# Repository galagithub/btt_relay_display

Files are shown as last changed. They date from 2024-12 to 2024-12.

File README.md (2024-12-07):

## BTT Relay Display

A small PCB that can display the status of the relay, it connects to it through a 5 pin cable. A reset switch is also provided.
You can also program/flash the relay through it, there is a separate header for programmer connection.

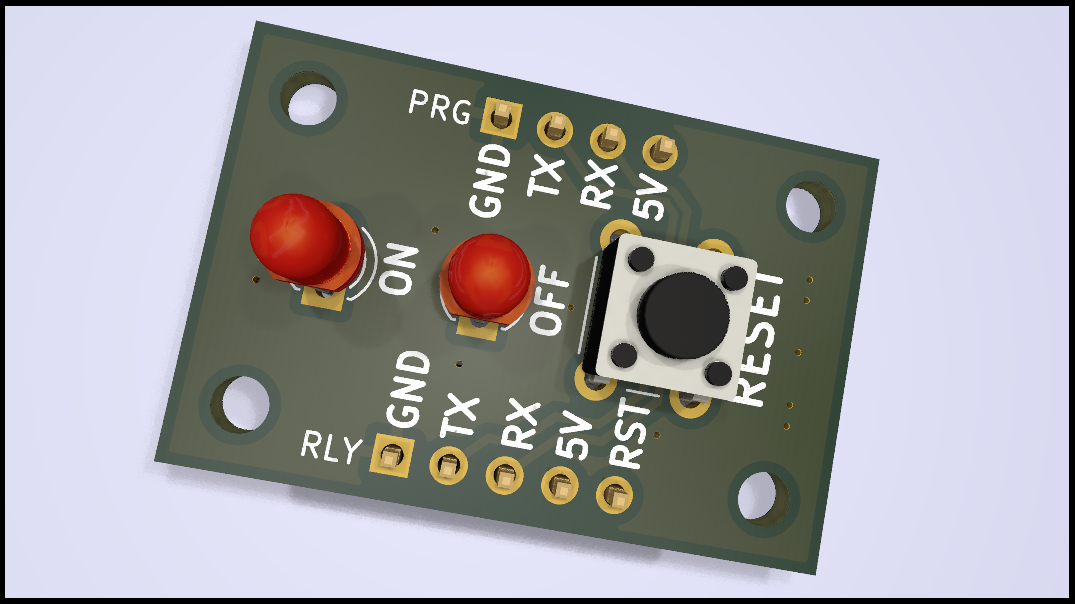
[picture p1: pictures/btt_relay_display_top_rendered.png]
PCB top render


### Related projects
- BTT Relay v1.2 https://github.com/bigtreetech/BIGTREETECH-Relay-V1.2
- Custom firmware with platform.io https://github.com/galagithub/btt_relay_os

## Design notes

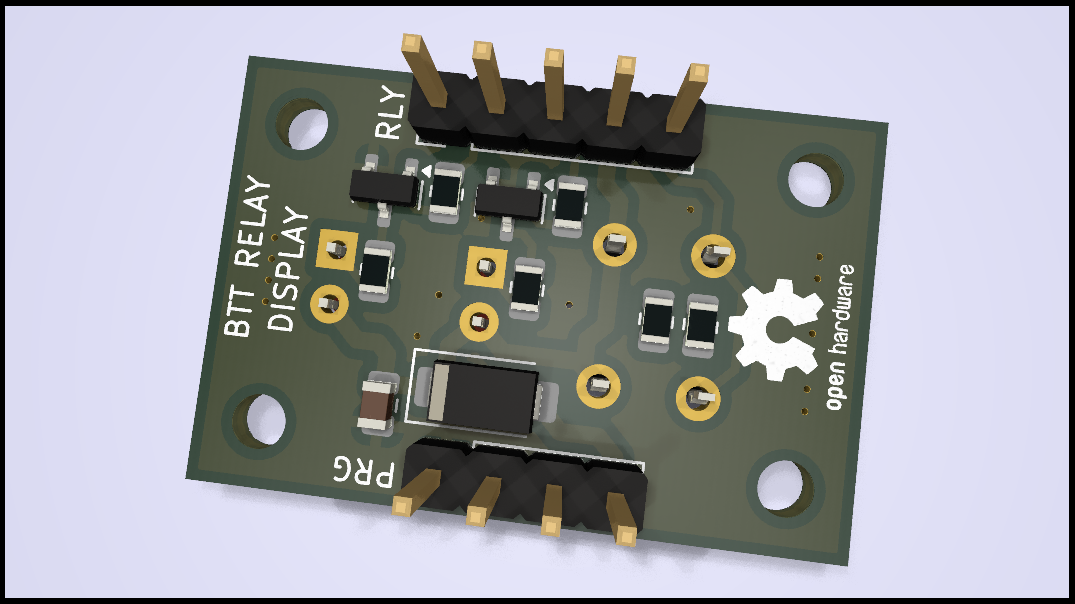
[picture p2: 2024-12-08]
pictures/btt_relay_display_bot_rendered.png

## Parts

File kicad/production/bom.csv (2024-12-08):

Designator | Footprint | Quantity | Value | LCSC Part #
C1 | 0805 | 1 | 1u
D1 | LED_D3.0mm | 1 | OFF (RED)
D2 | LED_D3.0mm | 1 | ON (GRN)
D3 | D_SMA | 1 | SS14
J1 | PinHeader_1x05_P2.54mm_Vertical | 1 | RELAY
J2 | PinHeader_1x04_P2.54mm_Vertical | 1 | PROGRAM
Q1, Q2 | SOT-23 | 2 | BC847
R1, R2, R3, R4 | 0805 | 4 | 1k
R5, R6 | 0805 | 2 | 470
SW1 | SW_PUSH_6mm_H5mm | 1 | RESET

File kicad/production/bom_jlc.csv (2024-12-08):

Designator | Footprint | Quantity | Value | LCSC Part #
C1 | 805 | 1 | 1u
D3 | D_SMA | 1 | SS14
Q1, Q2 | SOT-23 | 2 | BC847
R1, R2, R3, R4 | 805 | 4 | 1k
R5, R6 | 805 | 2 | 470

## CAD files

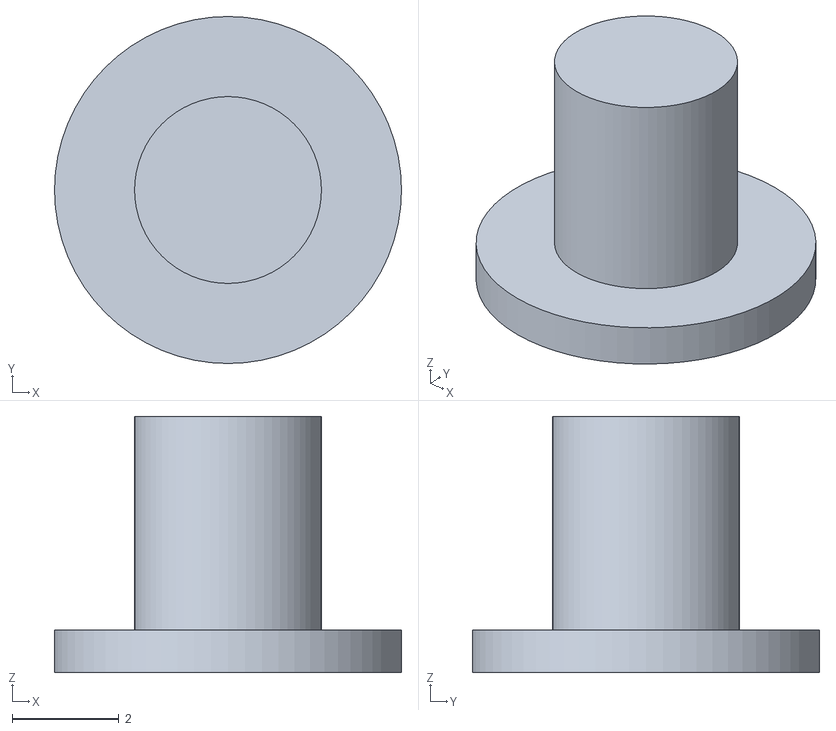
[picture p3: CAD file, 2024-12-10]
stl/front_face_button.stl
6.50 x 6.50 x 4.80

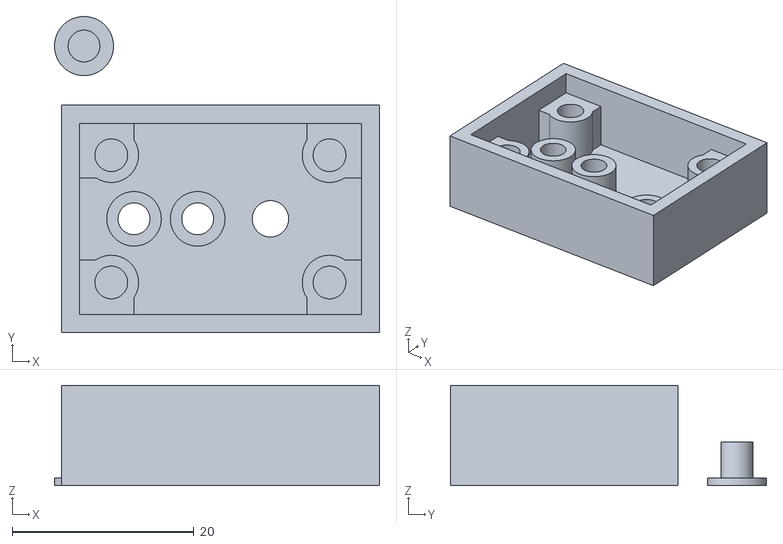
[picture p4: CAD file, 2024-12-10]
stl/front_face_with_button.stl
35.8 x 34.8 x 11.0

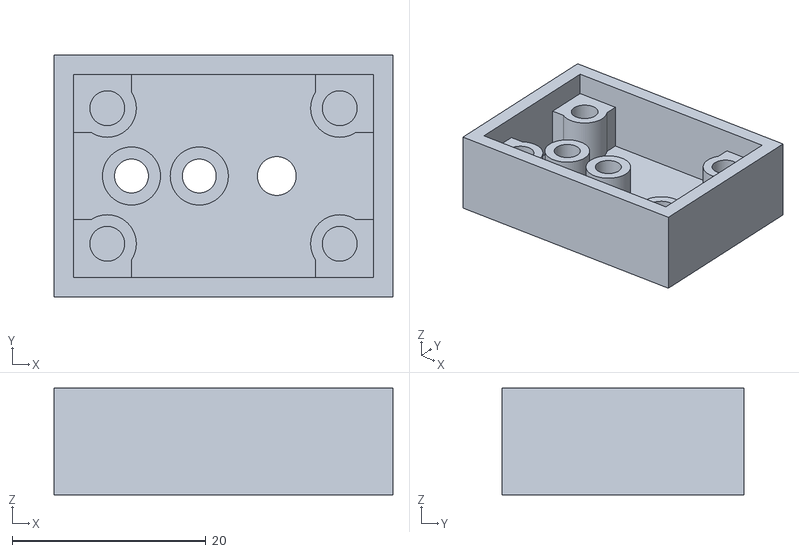
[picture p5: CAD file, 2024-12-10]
stl/front_face.stl
35.0 x 25.0 x 11.0

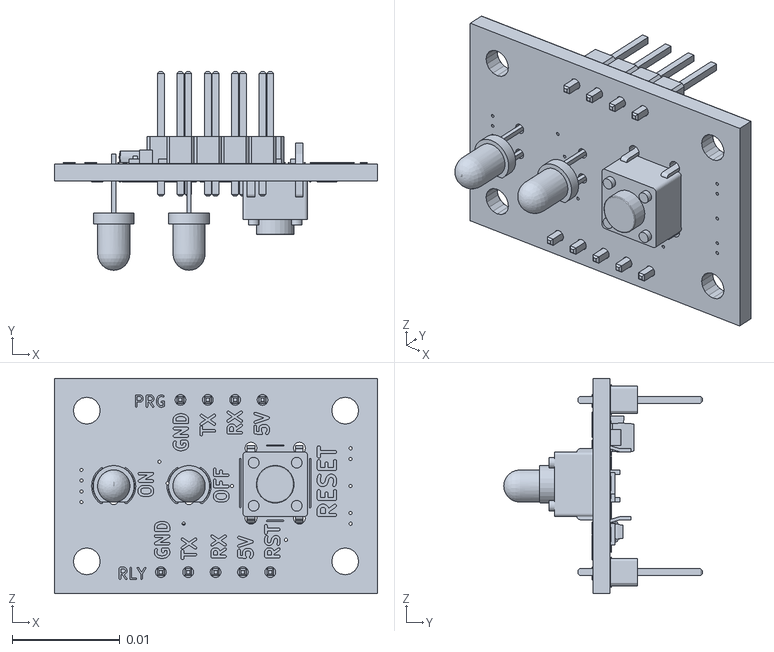
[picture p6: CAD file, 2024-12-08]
stl/btt_relay_display_v1.stl
0.03 x 0.0184 x 0.02

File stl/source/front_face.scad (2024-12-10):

// LICENSE: Attribution 4.0 International
// Copyright: Dragos GALALAE - 2024
//
// front face shell
//
// requires 4 M2.5 heat inserts!

pcb_x = 30;
pcb_y = 20;
pcb_tolerance = 1;
pcb_thickness = 2;
screws_x = 24;
screws_y = 14;
screws_mth_peg_z = 8;
screws_mth_peg_dia = 6;
screws_mth_insert_dia = 3.6;
led_on_x = 5.5;
led_on_y = 10;
led_off_x = 12.5;
led_off_y = 10;
led_hole_dia = 3.5;
led_peg_dia = 6;
led_peg_z = 6;
btn_x = 20.5;
btn_y = 10;
btn_hole_dia = 4;
btn_peg_dia = 8;
btn_peg_z = 2;
btn_hat_lip_thick = 0.8;
btn_hat_lip_dia = btn_peg_dia-1.5;
btn_hat_z = 4;
btn_hat_dia = btn_hole_dia-0.5;
face_wall = 2;
text_depth = 0.4;
text_size = 2.5;
text_above = 1;
do_button_hat = 1;

screws_mth_insert_depth = screws_mth_peg_z-face_wall;
pcb_hole_x = pcb_x+pcb_tolerance;
pcb_hole_y = pcb_y+pcb_tolerance;
screws_x_offset = (pcb_hole_x-screws_x)/2-pcb_tolerance/2;
screws_y_offset = (pcb_hole_y-screws_y)/2-pcb_tolerance/2;
pcb_hole_z = screws_mth_peg_z+pcb_thickness+pcb_tolerance;
text_position = (text_above)?(-(btn_hole_dia+1)):(btn_hole_dia+1);
$fn=64;

// front face
difference()
{
    // main body 
    union() {
        // pcb mth pegs
        translate([screws_x_offset,screws_y_offset,0]) {
            translate([0,0,0]) cylinder(screws_mth_peg_z,screws_mth_peg_dia/2,screws_mth_peg_dia/2);
            translate([screws_x,0,0]) cylinder(screws_mth_peg_z,screws_mth_peg_dia/2,screws_mth_peg_dia/2);
            translate([screws_x,screws_y,0]) cylinder(screws_mth_peg_z,screws_mth_peg_dia/2,screws_mth_peg_dia/2);
            translate([0,screws_y,0]) cylinder(screws_mth_peg_z,screws_mth_peg_dia/2,screws_mth_peg_dia/2);
        }
        // pcb pegs stiffner left bottom
        for(a=[0,screws_mth_peg_dia/2])
            translate([-pcb_tolerance/2+a,-pcb_tolerance/2,0]) cube([screws_mth_peg_dia/2,screws_mth_peg_dia/2,screws_mth_peg_z]);
        translate([-pcb_tolerance/2,-pcb_tolerance/2+screws_mth_peg_dia/2,0]) cube([screws_mth_peg_dia/2,screws_mth_peg_dia/2,screws_mth_peg_z]);
        // pcb pegs stiffner right bottom
        for(a=[1,2])
            translate([pcb_hole_x-screws_mth_peg_dia/2*a-pcb_tolerance/2,-pcb_tolerance/2,0]) cube([screws_mth_peg_dia/2,screws_mth_peg_dia/2,screws_mth_peg_z]);
        translate([pcb_hole_x-screws_mth_peg_dia/2-pcb_tolerance/2,screws_mth_peg_dia/2-pcb_tolerance/2,0]) cube([screws_mth_peg_dia/2,screws_mth_peg_dia/2,screws_mth_peg_z]);
        // pcb pegs stiffner right upper
        for(a=[1,2])
            translate([pcb_hole_x-screws_mth_peg_dia/2*a-pcb_tolerance/2,pcb_hole_y-screws_mth_peg_dia/2-pcb_tolerance/2,0]) cube([screws_mth_peg_dia/2,screws_mth_peg_dia/2,screws_mth_peg_z]);
        translate([pcb_hole_x-screws_mth_peg_dia/2-pcb_tolerance/2,pcb_hole_y-screws_mth_peg_dia-pcb_tolerance/2,0]) cube([screws_mth_peg_dia/2,screws_mth_peg_dia/2,screws_mth_peg_z]);
        // pcb pegs stiffner left upper
        for(a=[0,screws_mth_peg_dia/2])
            translate([-pcb_tolerance/2+a,pcb_hole_y-screws_mth_peg_dia/2-pcb_tolerance/2,0]) cube([screws_mth_peg_dia/2,screws_mth_peg_dia/2,screws_mth_peg_z]);
        translate([-pcb_tolerance/2,pcb_hole_y-screws_mth_peg_dia-pcb_tolerance/2,0]) cube([screws_mth_peg_dia/2,screws_mth_peg_dia/2,screws_mth_peg_z]);
        // led pegs
        translate([led_on_x,led_on_y,0]) cylinder(led_peg_z,led_peg_dia/2,led_peg_dia/2);
        translate([led_off_x,led_off_y,0]) cylinder(led_peg_z,led_peg_dia/2,led_peg_dia/2);
        // button
        translate([btn_x,btn_y,0]) cylinder(btn_peg_z,btn_peg_dia/2,btn_peg_dia/2);
        // face
        translate([-pcb_tolerance/2,-pcb_tolerance/2,0]) cube([pcb_hole_x,pcb_hole_y,face_wall]);
        // wall left
        translate([-pcb_tolerance/2-face_wall,-pcb_tolerance/2,0]) cube([face_wall,pcb_hole_y,pcb_hole_z]);
        // wall right
        translate([pcb_hole_x-pcb_tolerance/2,-pcb_tolerance/2,0]) cube([face_wall,pcb_hole_y,pcb_hole_z]);
        // wall bot
        translate([-pcb_tolerance/2-face_wall,-pcb_tolerance/2-face_wall,0]) cube([pcb_hole_x+2*face_wall,face_wall,pcb_hole_z]);
        // wall top
        translate([-pcb_tolerance/2-face_wall,pcb_hole_y-pcb_tolerance/2,0]) cube([pcb_hole_x+2*face_wall,face_wall,pcb_hole_z]);
    }
    // cutouts
    union() {
        // pcb mth holes
        translate([screws_x_offset,screws_y_offset,screws_mth_peg_z-screws_mth_insert_depth]) {
            translate([0,0,0]) cylinder(screws_mth_insert_depth+0.01,screws_mth_insert_dia/2,screws_mth_insert_dia/2);
            translate([screws_x,0,0]) cylinder(screws_mth_insert_depth+0.01,screws_mth_insert_dia/2,screws_mth_insert_dia/2);
            translate([screws_x,screws_y,0]) cylinder(screws_mth_insert_depth+0.01,screws_mth_insert_dia/2,screws_mth_insert_dia/2);
            translate([0,screws_y,0]) cylinder(screws_mth_insert_depth+0.01,screws_mth_insert_dia/2,screws_mth_insert_dia/2);
        }
        // led holes
        translate([led_on_x,led_on_y,-0.005]) cylinder(led_peg_z+0.01,led_hole_dia/2,led_hole_dia/2);
        translate([led_off_x,led_off_y,-0.005]) cylinder(led_peg_z+0.01,led_hole_dia/2,led_hole_dia/2);
        // button hole
        translate([btn_x,btn_y,-0.005]) cylinder(btn_peg_z+0.01,btn_hole_dia/2,btn_hole_dia/2);
        // "text" on
        translate([led_on_x,led_on_y+text_position,-0.005]) rotate([0,0,180])
        mirror([1,0,0]) linear_extrude(height=text_depth) {
            text("I",size=text_size,font="Verdana:style=Bold",direction="ltr",halign="center",valign="center");
        }
        // "text" off
        translate([led_off_x,led_off_y+text_position,-0.005]) rotate([0,0,180])
        mirror([1,0,0]) linear_extrude(height=text_depth) {
            text("O",size=text_size,font="Verdana:style=Bold",direction="ltr",halign="center",valign="center");
        }
        // "text" reset
        translate([btn_x,btn_y+text_position,-0.005]) rotate([0,0,180])
        mirror([1,0,0]) linear_extrude(height=text_depth) {
            text("R",size=text_size,font="Verdana:style=Bold",direction="ltr",halign="center",valign="center");
        }
    }
}

if (do_button_hat)
{
    // reset button
    translate([0,pcb_hole_y+btn_peg_dia/2+face_wall+2,0]) {
        cylinder(btn_hat_lip_thick,btn_hat_lip_dia/2,btn_hat_lip_dia/2);
        cylinder(btn_hat_z+btn_hat_lip_thick,btn_hat_dia/2,btn_hat_dia/2);
    }
}

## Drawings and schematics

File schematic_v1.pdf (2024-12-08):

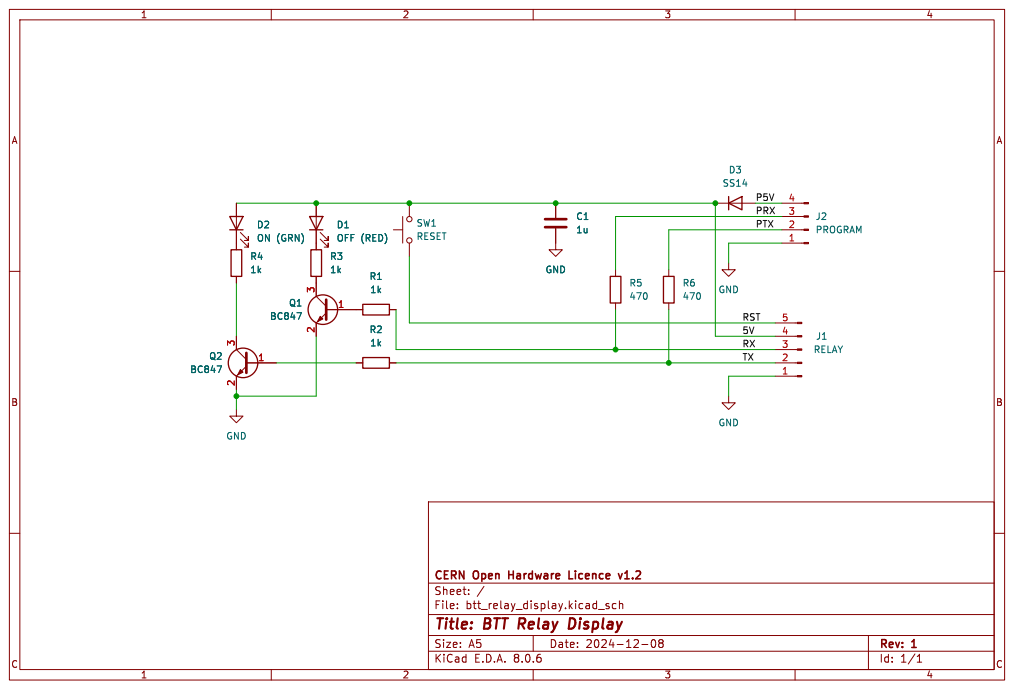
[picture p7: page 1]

Sheet: /
Title: BTT Relay Display

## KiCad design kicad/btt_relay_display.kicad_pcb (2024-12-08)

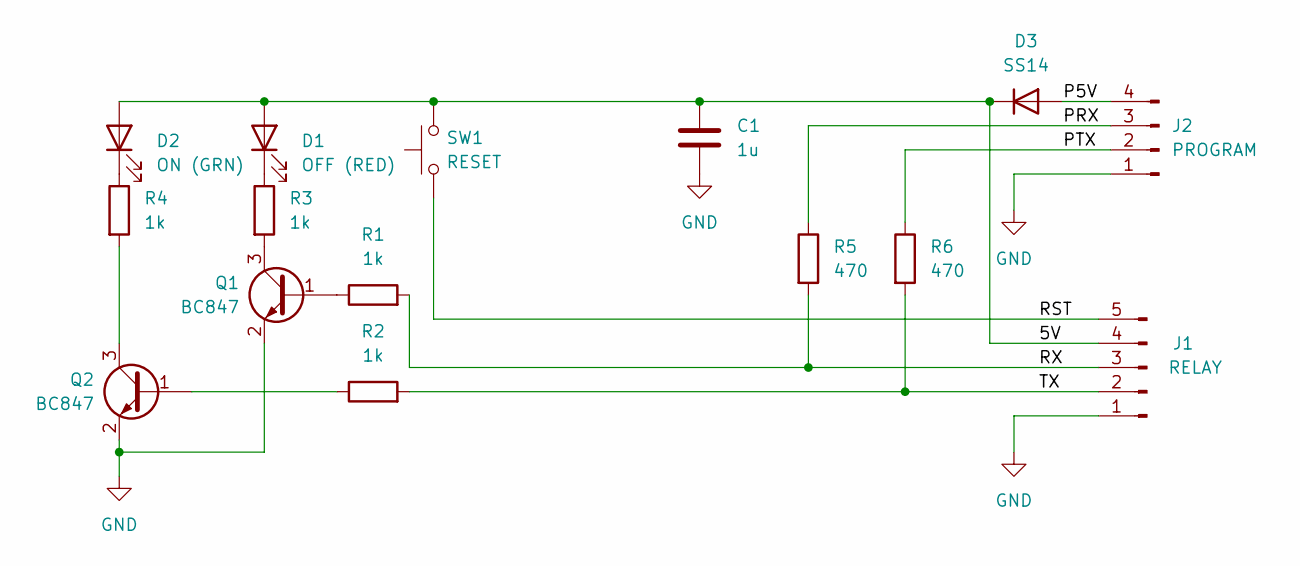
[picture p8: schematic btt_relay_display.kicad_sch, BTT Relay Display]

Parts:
C1: 1u; C_0805_2012Metric
D1: OFF (RED); LED_D3.0mm
D2: ON (GRN); LED_D3.0mm
D3: SS14; D_SMA
J1: RELAY; PinHeader_1x05_P2.54mm_Vertical
J2: PROGRAM; PinHeader_1x04_P2.54mm_Vertical
Q1, Q2: BC847; SOT-23
R1, R2, R3, R4: 1k; R_0805_2012Metric
R5, R6: 470; R_0805_2012Metric
SW1: RESET; SW_PUSH_6mm_H5mm

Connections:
/5V: C1.1, D1.2 (A), D2.2 (A), D3.1 (K), J1.4, SW1.1
/P5V: D3.2 (A), J2.4
/PRX: J2.3, R5.1
/PTX: J2.2, R6.1
/RST: J1.5, SW1.2
/RX: J1.3, R1.2, R5.2
/TX: J1.2, R2.2, R6.2
GND: C1.2, J1.1, J2.1, Q1.2 (E), Q2.2 (E)
unnamed: D1.1 (K), R3.1
unnamed: D2.1 (K), R4.1
unnamed: Q1.1 (B), R1.1
unnamed: Q1.3 (C), R3.2
unnamed: Q2.1 (B), R2.1
unnamed: Q2.3 (C), R4.2

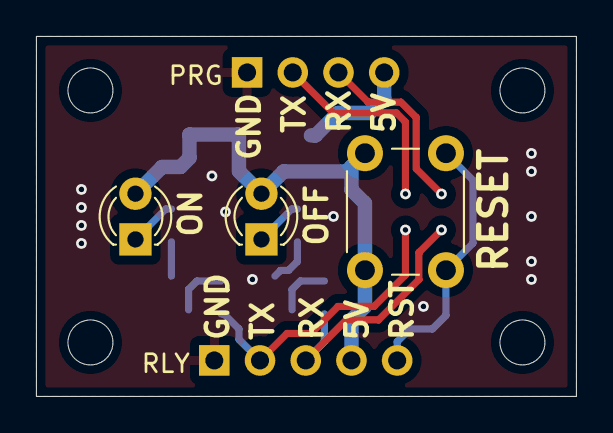
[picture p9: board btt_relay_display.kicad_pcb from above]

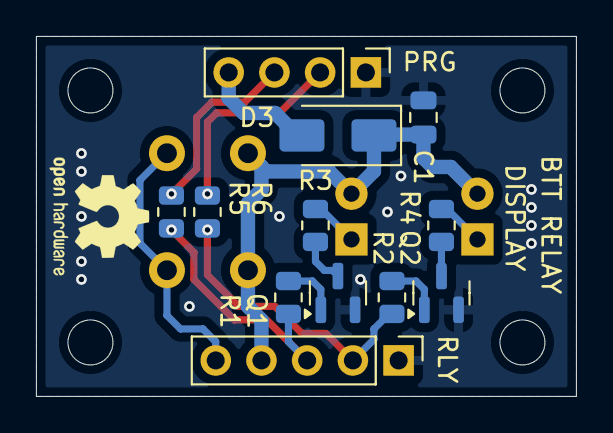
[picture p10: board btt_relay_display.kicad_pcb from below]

Board: 2 copper layers, 30.0 x 20.0 mm, 15 parts (12 on the bottom side), 14 nets.

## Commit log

2024-12-07 Add stl dir
2024-12-07 Update PCB to include OHW logo and position reference text properly.
    [btt_relay_display.kicad_pcb]
2024-12-07 Add rendered pictures of PCB
2024-12-07 show top pcb render in readme
2024-12-08 Holes made 2.5mm add pcb name text, generate gerbes for jlcpcb assembly service
    [bom.csv, bom_jlc.csv, btt_relay_display.kicad_pcb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]
2024-12-08 PCB v1 stl export
    [btt_relay_display_v1.stl]
2024-12-09 Initial front face for mounting box, just source.
    [front_face.scad]
2024-12-09 Initial front face for mounting box, the stl
    [front_face.stl]
2024-12-10 Update front face stl design, to be tested.
    [front_face.scad, front_face.stl, front_face_button.stl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]

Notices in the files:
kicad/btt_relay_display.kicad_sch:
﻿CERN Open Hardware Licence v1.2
